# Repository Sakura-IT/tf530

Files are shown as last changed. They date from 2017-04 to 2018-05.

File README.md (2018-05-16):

# TF530 Revision 3

WARNING: This board has not been CE tested. It may cause damage to your A500. I take no responsibility for this. 

This repository contains all the files needed to produce a copy of my accelerator board.

The CPLD Required is a XC9572XL-10VQ64.  The CPLD XC9572XL-10VQG64 is the readily available RoHS "Green" lead-free equivalent.

Everything in this repository is released under the GNU GPLv2. You may create or base commercial PCBs from the work in this repository but you must make the sources for all derivative work available. I have noticed some forks have removed copyright notices. This is a breach of the GPL.

## Firmware / Requirements

  * Xilinx ISE, 14.7 (the final version - other versions may work but this is the one I support)
  * JTAG Adaptor

[For more information visit my channel](https://www.youtube.com/c/TerribleFire)

## License

This project and all the files contained are released under the GNU GPLv2. If you build a modified version of the board you must supply the end user with all the sources (this can be a web link).

## The TerribleFire 530 board (Revision 3)

Completely untested board link.... use with caution!!!! Do not come crying to me if it didnt work!!

http://dirtypcbs.com/store/designer/details/12476/2654/tf530-rev3-zip

## The TerribleFire 530 board (Revision 2)

This board is now in Beta. It may not work in all circumstances but it has been verified to boot AmigaOS 1.3, 2.05 and 3.1 and run various games and desktop apps at 25Mhz. Operation is not guarunteed to be crash free but will work in most "happy path" situations.

I have only verified the HD interface with Compact Flash cards.
I have verified this board boots on Amiga 500 Rev 5, 6a, 8.1a

I accept no responsibiltiy for any damage to any equipment that results from the use of this board. IT IS ENTIRELY AT YOUR OWN RISK!

## Installation

As of Revision 3 installation no longer needs the OVR and INT2 signals connected to the Amiga motherboard. The headers remain on the TF530 for testing but do not need to be connected although it should make little difference if they are connected. Well behaved Autoconfig devices will work alongside the TF530. The autoconfig space asserts the internal OVR signal when there are PICs remaining to be configured. After which the autoconfig will probe the standard bus. This revision should work on the A2000 (untested).

IPL0 has not been routed because we only ever need to assert INT2 and/or INT6.

## What does the board look like

The TF530 Rev 3 looks like...

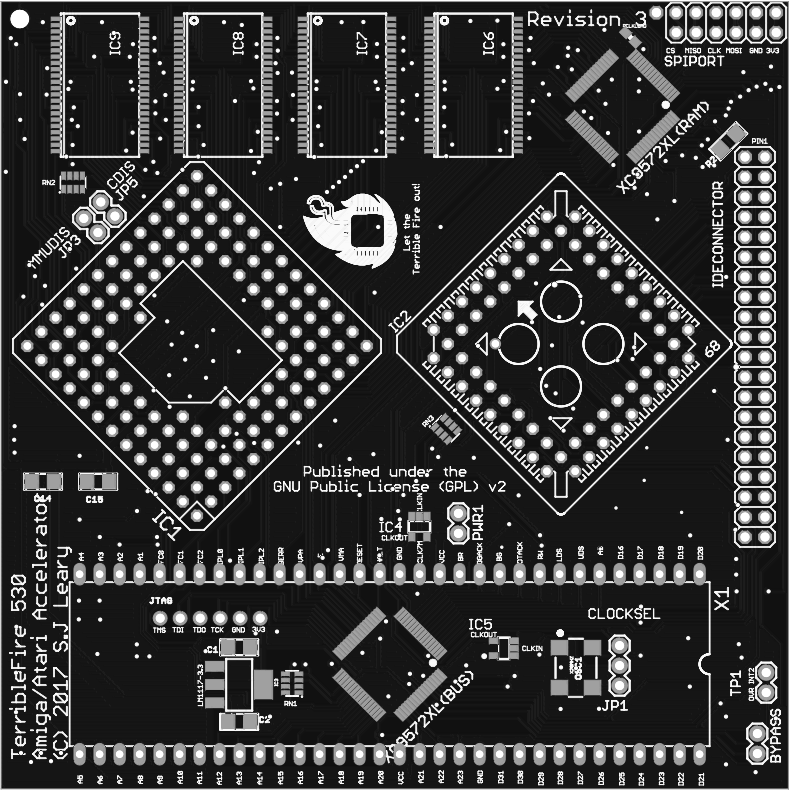
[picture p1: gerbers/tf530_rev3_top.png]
Image of Top of PCB


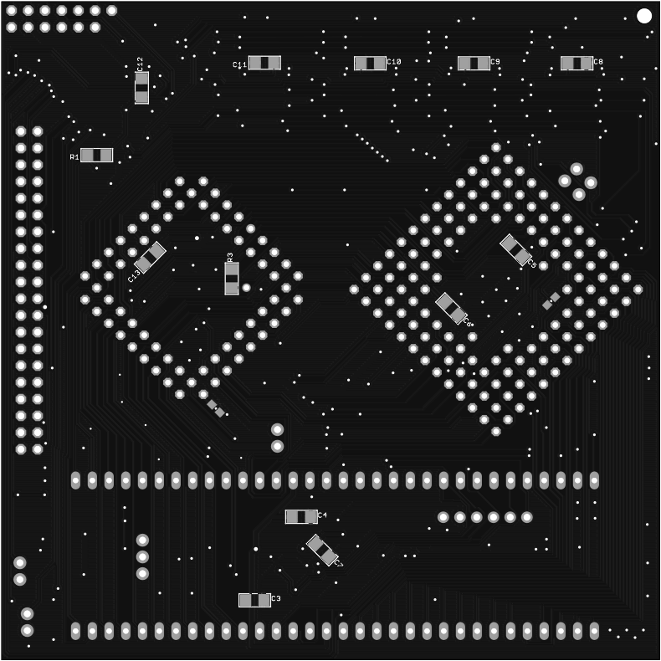
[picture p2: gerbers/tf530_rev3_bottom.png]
Image of Bottom of PCB


## The Rev 3 BOM (WARNING! This is untested)

| Qty | Value | Device | Package | Parts | Description |
|-----|---|---|---|---|---|
| 1 | | MC68030RC | MPGA128 | IC1 | 68030 PROCESSOR |
| 1 | | MC68882FN | PLCC68-S | IC2 | 68882 CO-PROCESSOR (FPU) + PLCC68 Thru Hole Socket |
| 2 | 0.1uF | 0.1UF-25V(+80/-20%)| 0603-CAP | C16, C17 | CAP-00810 |
| 15  | 10uF | CAP_CERAMIC1206 | 1206 | C1, C2, C3, C4, C5, C6, C7, C8, C9, C10, C11, C12, C13, C14, C15 | Ceramic Capacitors |
| 3 | 1K | RESISTOR1206 | 1206 | R1, R2, R3 | Resistors |
| 2 | 74LVC1G17DBV | 74LVC1G17DBV | SOT23-5 | IC4, IC5 | Single Schmitt-Trigger Buffer |
| 4 | AS7C4096A-12TCN | AS7C4096A-12TCN | TSOP44-II | IC6, IC7, IC8, IC9 | SRAM 512k x 8, 5V DO NOT USE ISSI Chips!! |
| 1 | BYPASS | JUMPER-2PTH | 1X02 | BYPASS | Jumper |
| 3 | CAY16-102J4LF | CAY16-102J4LF | RESCAXE80P320X160-8N | RN1, RN2, RN3 | Res Thick Film Array 1K Ohm  |
| 1 | CDIS | JUMPER-2PTH | 1X02 | JP5 | Jumper |
| 1 | CLOCKSEL | JUMPER-3PTH | 1X03 | JP1 | Jumper |
| 1 | EXT5V | JUMPER-2PTH | 1X02 | PWR1 | Jumper |
| 1 | IDE CONNECTOR | PINHD-2X20 | 2X20 | IDECONNECTOR | PIN HEADER |
| 1 | INF | 0.05OHM-1/5W-1% | 0603 | RCLKLOAD | Not Required - Experimental |
| 1 | JTAG | HEADER-1X6ROUND | 1X06_ROUND | JTAG | PIN HEADER |
| 1 | LM1117-3.3 | V_REG_LM1117SOT223 | SOT223 | IC3 | 3.3V Voltage Regulator LM1117 |
| 1 | MC68000 | MC68000P | DIL64 | X1 | 68xxx CPU Slot Strip Headers  |
| 1 | MMUDIS | JUMPER-2PTH | 1X02 | JP3 | Jumper |
| 1 | SPI PORT | PINHD-2X6 | 2X06 | SPIPORT | PIN HEADER |
| 1 | TP1 | JUMPER-2PTH | 1X02 | TP1 | Jumper |
| 1 | X25MHZ | OSCILLATOR | OSC_7X5MM | OSC1 | Oscillator e.g. 25MHz |
| 2 | XC9572XL-VQ64 | XC9572XL-VQ64 | VQ64 | XC9572XL(BUS), XC9572XL(RAM) | Xilinx CPLD |

### Notes

* _The CPU and (optional) FPU must be 25MHz/33Mhz capable._

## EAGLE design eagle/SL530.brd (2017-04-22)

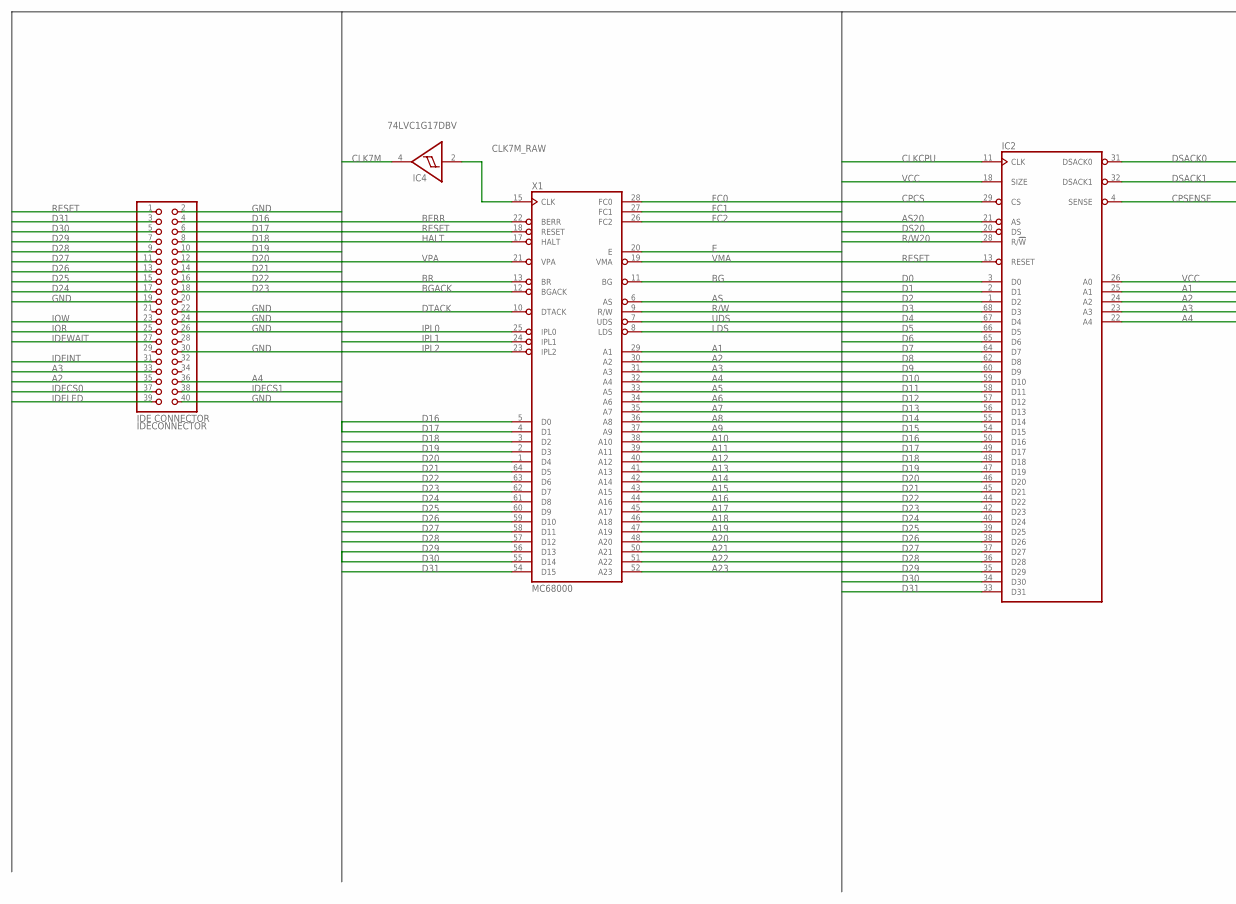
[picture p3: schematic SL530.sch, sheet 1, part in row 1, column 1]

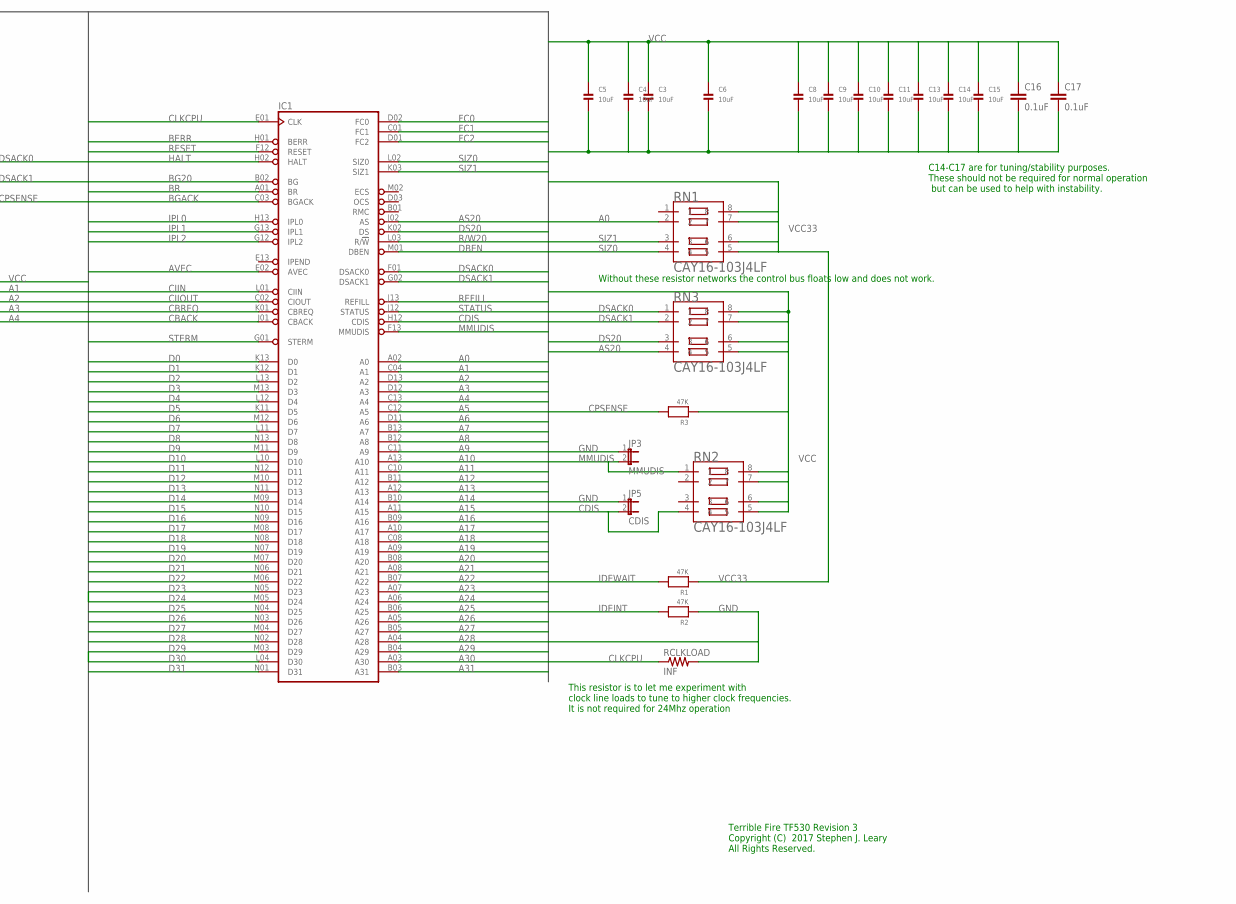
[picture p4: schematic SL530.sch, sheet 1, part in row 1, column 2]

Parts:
C3, C4, C5, C6, C8, C9, C10, C11, C13, C14, C15: 10uF; 1206
C16, C17: 0.1uF; 0603-CAP
IC1: MC68030RC; MPGA128
IC2: MC68881FN-SOC; PLCC68-S
IC4: 74LVC1G17DBV; SOT23-5
IDECONNECTOR: IDE CONNECTOR; 2X20
JP3: MMUDIS; 1X02
JP5: CDIS; 1X02
R1, R2, R3: 47K; 1206
RCLKLOAD: INF; 0603
RN1, RN2, RN3: CAY16-103J4LF; RESCAXE80P320X160-8N
X1: MC68000; DIL64

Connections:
A0: IC1.A02 (A0), RN1.2; also elsewhere on the board
A1: IC1.C04 (A1), IC2.25 (A1), X1.29 (A1); also elsewhere on the board
A2: IC1.D13 (A2), IC2.24 (A2), IDECONNECTOR.35, X1.30 (A2); also elsewhere on the board
A3: IC1.D12 (A3), IC2.23 (A3), IDECONNECTOR.33, X1.31 (A3); also elsewhere on the board
A4: IC1.C13 (A4), IC2.22 (A4), IDECONNECTOR.36, X1.32 (A4); also elsewhere on the board
A5: IC1.C12 (A5), X1.33 (A5); also elsewhere on the board
A6: IC1.D11 (A6), X1.34 (A6); also elsewhere on the board
A7: IC1.B13 (A7), X1.35 (A7); also elsewhere on the board
A8: IC1.B12 (A8), X1.36 (A8); also elsewhere on the board
A9: IC1.C11 (A9), X1.37 (A9); also elsewhere on the board
A10: IC1.A13 (A10), X1.38 (A10); also elsewhere on the board
A11: IC1.C10 (A11), X1.39 (A11); also elsewhere on the board
A12: IC1.B11 (A12), X1.40 (A12); also elsewhere on the board
A13: IC1.A12 (A13), X1.41 (A13); also elsewhere on the board
A14: IC1.B10 (A14), X1.42 (A14); also elsewhere on the board
A15: IC1.A11 (A15), X1.43 (A15); also elsewhere on the board
A16: IC1.B09 (A16), X1.44 (A16); also elsewhere on the board
A17: IC1.A10 (A17), X1.45 (A17); also elsewhere on the board
A18: IC1.C08 (A18), X1.46 (A18); also elsewhere on the board
A19: IC1.A09 (A19), X1.47 (A19); also elsewhere on the board
A20: IC1.B08 (A20), X1.48 (A20); also elsewhere on the board
A21: IC1.A08 (A21), X1.50 (A21); also elsewhere on the board
A22: IC1.B07 (A22), X1.51 (A22); also elsewhere on the board
A23: IC1.A07 (A23), X1.52 (A23); also elsewhere on the board
A24: IC1.A06 (A24)
A25: IC1.B06 (A25)
A26: IC1.A05 (A26)
A27: IC1.B05 (A27)
A28: IC1.A04 (A28)
A29: IC1.B04 (A29)
A30: IC1.A03 (A30)
A31: IC1.B03 (A31)
AS: X1.6 (AS); also elsewhere on the board
AS20: IC1.J02 (AS), IC2.21 (AS), RN3.4; also elsewhere on the board
AVEC: IC1.E02 (AVEC); also elsewhere on the board
BERR: IC1.H01 (BERR), X1.22 (BERR); also elsewhere on the board
BG: X1.11 (BG); also elsewhere on the board
BG20: IC1.B02 (BG); also elsewhere on the board
BGACK: IC1.C03 (BGACK), X1.12 (BGACK); also elsewhere on the board
BR: IC1.A01 (BR), X1.13 (BR)
CBACK: IC1.J01 (CBACK); also elsewhere on the board
CBREQ: IC1.K01 (CBREQ); also elsewhere on the board
CDIS: IC1.H12 (CDIS), JP5.2, RN2.4
CIIN: IC1.L01 (CIIN); also elsewhere on the board
CIIOUT: IC1.C02 (CIOUT)
CLK7M: IC4.4 (O); also elsewhere on the board
CLK7M_RAW: IC4.2 (I), X1.15 (CLK)
CLKCPU: IC1.E01 (CLK), IC2.11 (CLK), RCLKLOAD.1; also elsewhere on the board
CPCS: IC2.29 (CS); also elsewhere on the board
CPSENSE: IC2.4 (SENSE), R3.2; also elsewhere on the board
D0: IC1.K13 (D0), IC2.3 (D0); also elsewhere on the board
D1: IC1.K12 (D1), IC2.2 (D1); also elsewhere on the board
D2: IC1.L13 (D2), IC2.1 (D2); also elsewhere on the board
D3: IC1.M13 (D3), IC2.68 (D3); also elsewhere on the board
D4: IC1.L12 (D4), IC2.67 (D4); also elsewhere on the board
D5: IC1.K11 (D5), IC2.66 (D5); also elsewhere on the board
D6: IC1.M12 (D6), IC2.65 (D6); also elsewhere on the board
D7: IC1.L11 (D7), IC2.64 (D7); also elsewhere on the board
D8: IC1.N13 (D8), IC2.62 (D8); also elsewhere on the board
D9: IC1.M11 (D9), IC2.60 (D9); also elsewhere on the board
D10: IC1.L10 (D10), IC2.59 (D10); also elsewhere on the board
D11: IC1.N12 (D11), IC2.58 (D11); also elsewhere on the board
D12: IC1.M10 (D12), IC2.57 (D12); also elsewhere on the board
D13: IC1.N11 (D13), IC2.56 (D13); also elsewhere on the board
D14: IC1.M09 (D14), IC2.55 (D14); also elsewhere on the board
D15: IC1.N10 (D15), IC2.54 (D15); also elsewhere on the board
D16: IC1.N09 (D16), IC2.50 (D16), IDECONNECTOR.4, X1.5 (D0); also elsewhere on the board
D17: IC1.M08 (D17), IC2.49 (D17), IDECONNECTOR.6, X1.4 (D1); also elsewhere on the board
D18: IC1.N08 (D18), IC2.48 (D18), IDECONNECTOR.8, X1.3 (D2); also elsewhere on the board
D19: IC1.N07 (D19), IC2.47 (D19), IDECONNECTOR.10, X1.2 (D3); also elsewhere on the board
D20: IC1.M07 (D20), IC2.46 (D20), IDECONNECTOR.12, X1.1 (D4); also elsewhere on the board
D21: IC1.N06 (D21), IC2.45 (D21), IDECONNECTOR.14, X1.64 (D5); also elsewhere on the board
D22: IC1.M06 (D22), IC2.44 (D22), IDECONNECTOR.16, X1.63 (D6); also elsewhere on the board
D23: IC1.N05 (D23), IC2.42 (D23), IDECONNECTOR.18, X1.62 (D7); also elsewhere on the board
D24: IC1.M05 (D24), IC2.40 (D24), IDECONNECTOR.17, X1.61 (D8); also elsewhere on the board
D25: IC1.N04 (D25), IC2.39 (D25), IDECONNECTOR.15, X1.60 (D9); also elsewhere on the board
D26: IC1.N03 (D26), IC2.38 (D26), IDECONNECTOR.13, X1.59 (D10); also elsewhere on the board
D27: IC1.M04 (D27), IC2.37 (D27), IDECONNECTOR.11, X1.58 (D11); also elsewhere on the board
D28: IC1.N02 (D28), IC2.36 (D28), IDECONNECTOR.9, X1.57 (D12); also elsewhere on the board
D29: IC1.M03 (D29), IC2.35 (D29), IDECONNECTOR.7, X1.56 (D13); also elsewhere on the board
D30: IC1.L04 (D30), IC2.34 (D30), IDECONNECTOR.5, X1.55 (D14); also elsewhere on the board
D31: IC1.N01 (D31), IC2.33 (D31), IDECONNECTOR.3, X1.54 (D15); also elsewhere on the board
DBEN: IC1.M01 (DBEN)
DS20: IC1.K02 (DS), IC2.20 (DS), RN3.3; also elsewhere on the board
DSACK0: IC1.F01 (DSACK0), IC2.31 (DSACK0), RN3.1
DSACK1: IC1.G02 (DSACK1), IC2.32 (DSACK1), RN3.2; also elsewhere on the board
DTACK: X1.10 (DTACK); also elsewhere on the board
E: X1.20 (E); also elsewhere on the board
FC0: IC1.D02 (FC0), X1.28 (FC0); also elsewhere on the board
FC1: IC1.C01 (FC1), X1.27 (FC1); also elsewhere on the board
FC2: IC1.D01 (FC2), X1.26 (FC2); also elsewhere on the board
GND: C3.2, C4.2, C5.2, C6.2, C8.2, C9.2, C10.2, C11.2, C13.2, C14.2, C15.2, C16.2, C17.2, IC1.C05 (GND), IC1.C07 (GND), IC1.C09 (GND), IC1.E03 (GND), IC1.E11 (GND), IC1.F03 (GND), IC1.G03 (GND), IC1.G11 (GND), IC1.J03 (GND), IC1.J11 (GND), IC1.L05 (GND), IC1.L07 (GND), IC1.L08 (GND), IC1.L09 (GND), IC2.5 (GND), IC2.6 (GND), IC2.7 (GND), IC2.8 (GND), IC2.9 (GND), IC2.12 (GND), IC2.14 (GND), IC2.19 (GND), IC2.30 (GND), IC2.41 (GND), IC2.51 (GND), IC2.63 (GND), IC4.3 (GND), IDECONNECTOR.2, IDECONNECTOR.19, IDECONNECTOR.22, IDECONNECTOR.24, IDECONNECTOR.26, IDECONNECTOR.30, IDECONNECTOR.40, JP3.1, JP5.1, R2.1, RCLKLOAD.2, X1.16 (GND), X1.53 (GND); also elsewhere on the board
HALT: IC1.H02 (HALT), X1.17 (HALT); also elsewhere on the board
IDECS0: IDECONNECTOR.37; also elsewhere on the board
IDECS1: IDECONNECTOR.38; also elsewhere on the board
IDEINT: IDECONNECTOR.31, R2.2; also elsewhere on the board
IDELED: IDECONNECTOR.39
IDEWAIT: IDECONNECTOR.27, R1.2; also elsewhere on the board
IOR: IDECONNECTOR.25; also elsewhere on the board
IOW: IDECONNECTOR.23; also elsewhere on the board
IPL0: IC1.H13 (IPL0), X1.25 (IPL0)
IPL1: IC1.G13 (IPL1), X1.24 (IPL1); also elsewhere on the board
IPL2: IC1.G12 (IPL2), X1.23 (IPL2); also elsewhere on the board
LDS: X1.8 (LDS); also elsewhere on the board
MMUDIS: IC1.F13 (MMUDIS), JP3.2, RN2.1
R/W: X1.9 (R/W); also elsewhere on the board
R/W20: IC1.L03 (R/!W), IC2.28 (R/!W); also elsewhere on the board
REFILL: IC1.J13 (REFILL)
RESET: IC1.F12 (RESET), IC2.13 (RESET), IDECONNECTOR.1, X1.18 (RESET); also elsewhere on the board
SIZ0: IC1.L02 (SIZ0), RN1.4; also elsewhere on the board
SIZ1: IC1.K03 (SIZ1), RN1.3; also elsewhere on the board
STATUS: IC1.J12 (STATUS)
STERM: IC1.G01 (STERM); also elsewhere on the board
UDS: X1.7 (UDS); also elsewhere on the board
VCC: C3.1, C4.1, C5.1, C6.1, C8.1, C9.1, C10.1, C11.1, C13.1, C14.1, C15.1, C16.1, C17.1, IC1.C06 (VCC), IC1.D04 (VCC), IC1.D10 (VCC), IC1.F02 (VCC), IC1.F11 (VCC), IC1.H03 (VCC), IC1.H11 (VCC), IC1.K04 (VCC), IC1.K10 (VCC), IC1.L06 (VCC), IC2.10 (VCC), IC2.16 (VCC), IC2.17 (VCC), IC2.18 (SIZE), IC2.26 (A0), IC2.27 (VCC), IC2.43 (VCC), IC2.52 (VCC), IC2.53 (VCC), IC2.61 (VCC), IC4.5 (VCC), R3.1, RN2.5, RN2.6, RN2.7, RN2.8, RN3.5, RN3.6, RN3.7, RN3.8, X1.14 (VCC), X1.49 (VCC); also elsewhere on the board
VCC33: R1.1, RN1.5, RN1.6, RN1.7, RN1.8; also elsewhere on the board
VMA: X1.19 (VMA); also elsewhere on the board
VPA: X1.21 (VPA); also elsewhere on the board

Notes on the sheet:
This resistor is to let me experiment with clock line loads to tune to higher clock frequencies. It is not required for 24Mhz operation
C14-C17 are for tuning/stability purposes. These should not be required for normal operation but can be used to help with instability.
Without these resistor networks the control bus floats low and does not work.
Terrible Fire TF530 Revision 3 Copyright (C) 2017 Stephen J. Leary All Rights Reserved.

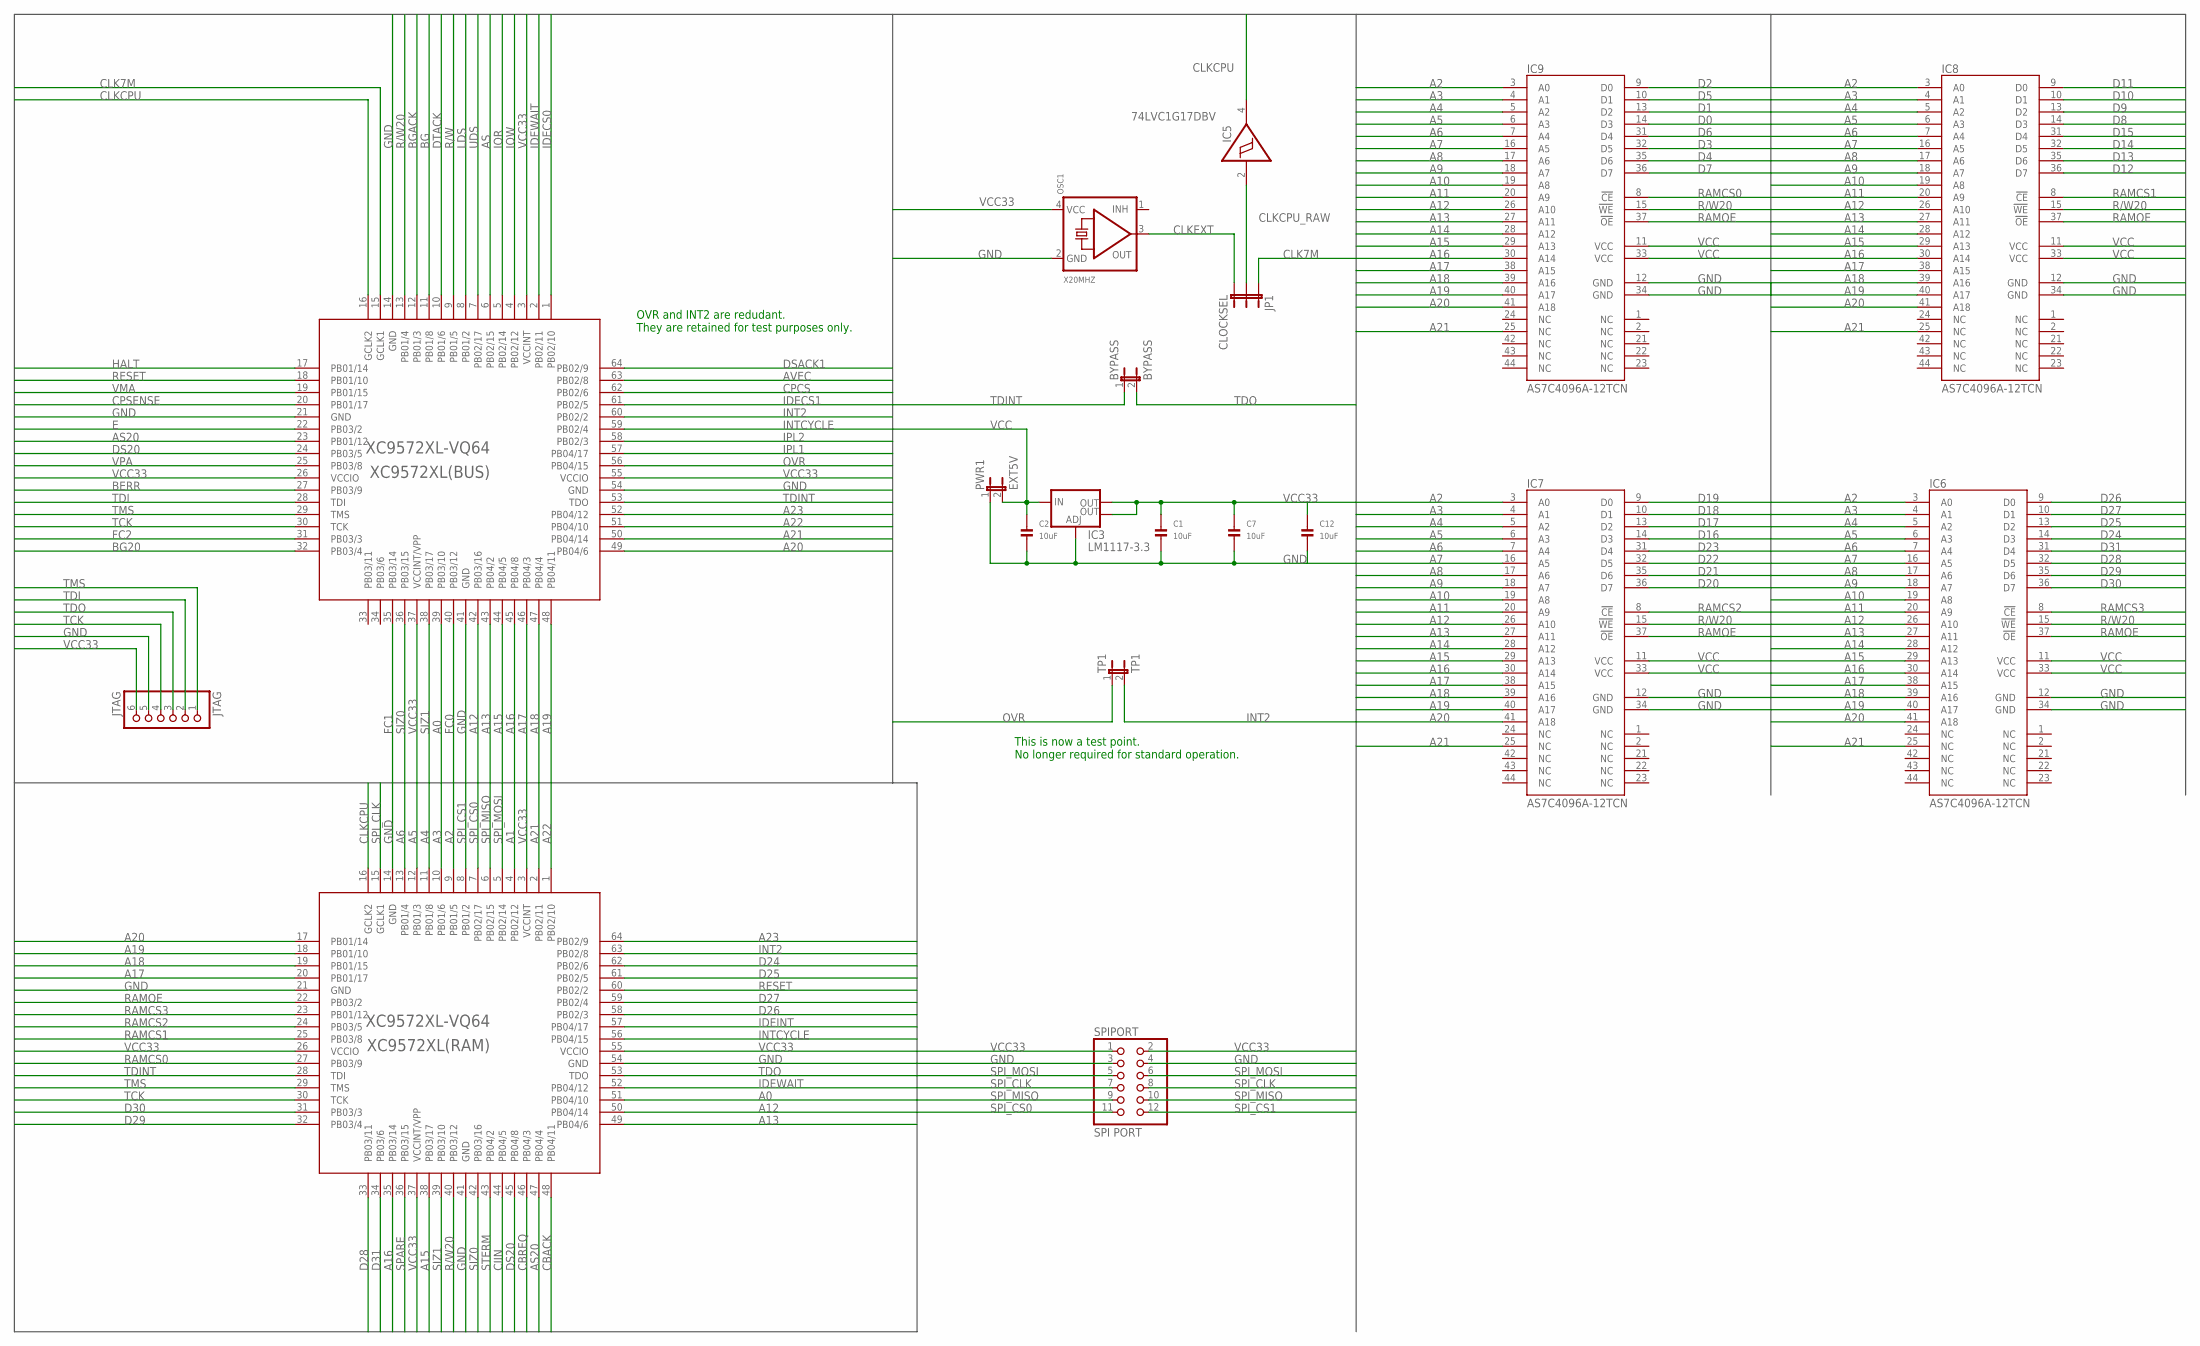
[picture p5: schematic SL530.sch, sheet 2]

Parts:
BYPASS: BYPASS; 1X02
C1, C2, C7, C12: 10uF; 1206
IC3: LM1117-3.3; SOT223
IC5: 74LVC1G17DBV; SOT23-5
IC6, IC7, IC8, IC9: AS7C4096A-12TCN; TSOP44-II
JP1: CLOCKSEL; 1X03
JTAG: JTAG; 1X06_ROUND
OSC1: X20MHZ; OSC_7X5MM
PWR1: EXT5V; 1X02
SPIPORT: SPI PORT; 2X06
TP1: TP1; 1X02
XC9572XL(BUS), XC9572XL(RAM): XC9572XL-VQ64; VQ64

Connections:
A0: XC9572XL(BUS).39 (PB03/10), XC9572XL(RAM).51 (PB04/10); also elsewhere on the board
A1: XC9572XL(RAM).4 (PB02/12); also elsewhere on the board
A2: IC6.3 (A0), IC7.3 (A0), IC8.3 (A0), IC9.3 (A0), XC9572XL(RAM).9 (PB01/5); also elsewhere on the board
A3: IC6.4 (A1), IC7.4 (A1), IC8.4 (A1), IC9.4 (A1), XC9572XL(RAM).10 (PB01/6); also elsewhere on the board
A4: IC6.5 (A2), IC7.5 (A2), IC8.5 (A2), IC9.5 (A2), XC9572XL(RAM).11 (PB01/8); also elsewhere on the board
A5: IC6.6 (A3), IC7.6 (A3), IC8.6 (A3), IC9.6 (A3), XC9572XL(RAM).12 (PB01/3); also elsewhere on the board
A6: IC6.7 (A4), IC7.7 (A4), IC8.7 (A4), IC9.7 (A4), XC9572XL(RAM).13 (PB01/4); also elsewhere on the board
A7: IC6.16 (A5), IC7.16 (A5), IC8.16 (A5), IC9.16 (A5); also elsewhere on the board
A8: IC6.17 (A6), IC7.17 (A6), IC8.17 (A6), IC9.17 (A6); also elsewhere on the board
A9: IC6.18 (A7), IC7.18 (A7), IC8.18 (A7), IC9.18 (A7); also elsewhere on the board
A10: IC6.19 (A8), IC7.19 (A8), IC8.19 (A8), IC9.19 (A8); also elsewhere on the board
A11: IC6.20 (A9), IC7.20 (A9), IC8.20 (A9), IC9.20 (A9); also elsewhere on the board
A12: IC6.26 (A10), IC7.26 (A10), IC8.26 (A10), IC9.26 (A10), XC9572XL(BUS).42 (PB03/16), XC9572XL(RAM).50 (PB04/14); also elsewhere on the board
A13: IC6.27 (A11), IC7.27 (A11), IC8.27 (A11), IC9.27 (A11), XC9572XL(BUS).43 (PB04/2), XC9572XL(RAM).49 (PB04/6); also elsewhere on the board
A14: IC6.28 (A12), IC7.28 (A12), IC8.28 (A12), IC9.28 (A12); also elsewhere on the board
A15: IC6.29 (A13), IC7.29 (A13), IC8.29 (A13), IC9.29 (A13), XC9572XL(BUS).44 (PB04/5), XC9572XL(RAM).38 (PB03/17); also elsewhere on the board
A16: IC6.30 (A14), IC7.30 (A14), IC8.30 (A14), IC9.30 (A14), XC9572XL(BUS).45 (PB04/8), XC9572XL(RAM).35 (PB03/14); also elsewhere on the board
A17: IC6.38 (A15), IC7.38 (A15), IC8.38 (A15), IC9.38 (A15), XC9572XL(BUS).46 (PB04/3), XC9572XL(RAM).20 (PB01/17); also elsewhere on the board
A18: IC6.39 (A16), IC7.39 (A16), IC8.39 (A16), IC9.39 (A16), XC9572XL(BUS).47 (PB04/4), XC9572XL(RAM).19 (PB01/15); also elsewhere on the board
A19: IC6.40 (A17), IC7.40 (A17), IC8.40 (A17), IC9.40 (A17), XC9572XL(BUS).48 (PB04/11), XC9572XL(RAM).18 (PB01/10); also elsewhere on the board
A20: IC6.41 (A18), IC7.41 (A18), IC8.41 (A18), IC9.41 (A18), XC9572XL(BUS).49 (PB04/6), XC9572XL(RAM).17 (PB01/14); also elsewhere on the board
A21: IC6.25 (NC), IC7.25 (NC), IC8.25 (NC), IC9.25 (NC), XC9572XL(BUS).50 (PB04/14), XC9572XL(RAM).2 (PB02/11); also elsewhere on the board
A22: XC9572XL(BUS).51 (PB04/10), XC9572XL(RAM).1 (PB02/10); also elsewhere on the board
A23: XC9572XL(BUS).52 (PB04/12), XC9572XL(RAM).64 (PB02/9); also elsewhere on the board
AS: XC9572XL(BUS).6 (PB02/15); also elsewhere on the board
AS20: XC9572XL(BUS).23 (PB01/12), XC9572XL(RAM).47 (PB04/4); also elsewhere on the board
AVEC: XC9572XL(BUS).63 (PB02/8); also elsewhere on the board
BERR: XC9572XL(BUS).27 (PB03/9); also elsewhere on the board
BG: XC9572XL(BUS).11 (PB01/8); also elsewhere on the board
BG20: XC9572XL(BUS).32 (PB03/4); also elsewhere on the board
BGACK: XC9572XL(BUS).12 (PB01/3); also elsewhere on the board
CBACK: XC9572XL(RAM).48 (PB04/11); also elsewhere on the board
CBREQ: XC9572XL(RAM).46 (PB04/3); also elsewhere on the board
CIIN: XC9572XL(RAM).44 (PB04/5); also elsewhere on the board
CLK7M: JP1.1, XC9572XL(BUS).15 (GCLK1); also elsewhere on the board
CLKCPU: IC5.4 (O), XC9572XL(BUS).16 (GCLK2), XC9572XL(RAM).16 (GCLK2); also elsewhere on the board
CLKCPU_RAW: IC5.2 (I), JP1.2
CLKEXT: JP1.3, OSC1.3 (OUT)
CPCS: XC9572XL(BUS).62 (PB02/6); also elsewhere on the board
CPSENSE: XC9572XL(BUS).20 (PB01/17); also elsewhere on the board
D0: IC9.14 (D3); also elsewhere on the board
D1: IC9.13 (D2); also elsewhere on the board
D2: IC9.9 (D0); also elsewhere on the board
D3: IC9.32 (D5); also elsewhere on the board
D4: IC9.35 (D6); also elsewhere on the board
D5: IC9.10 (D1); also elsewhere on the board
D6: IC9.31 (D4); also elsewhere on the board
D7: IC9.36 (D7); also elsewhere on the board
D8: IC8.14 (D3); also elsewhere on the board
D9: IC8.13 (D2); also elsewhere on the board
D10: IC8.10 (D1); also elsewhere on the board
D11: IC8.9 (D0); also elsewhere on the board
D12: IC8.36 (D7); also elsewhere on the board
D13: IC8.35 (D6); also elsewhere on the board
D14: IC8.32 (D5); also elsewhere on the board
D15: IC8.31 (D4); also elsewhere on the board
D16: IC7.14 (D3); also elsewhere on the board
D17: IC7.13 (D2); also elsewhere on the board
D18: IC7.10 (D1); also elsewhere on the board
D19: IC7.9 (D0); also elsewhere on the board
D20: IC7.36 (D7); also elsewhere on the board
D21: IC7.35 (D6); also elsewhere on the board
D22: IC7.32 (D5); also elsewhere on the board
D23: IC7.31 (D4); also elsewhere on the board
D24: IC6.14 (D3), XC9572XL(RAM).62 (PB02/6); also elsewhere on the board
D25: IC6.13 (D2), XC9572XL(RAM).61 (PB02/5); also elsewhere on the board
D26: IC6.9 (D0), XC9572XL(RAM).58 (PB02/3); also elsewhere on the board
D27: IC6.10 (D1), XC9572XL(RAM).59 (PB02/4); also elsewhere on the board
D28: IC6.32 (D5), XC9572XL(RAM).33 (PB03/11); also elsewhere on the board
D29: IC6.35 (D6), XC9572XL(RAM).32 (PB03/4); also elsewhere on the board
D30: IC6.36 (D7), XC9572XL(RAM).31 (PB03/3); also elsewhere on the board
D31: IC6.31 (D4), XC9572XL(RAM).34 (PB03/6); also elsewhere on the board
DS20: XC9572XL(BUS).24 (PB03/5), XC9572XL(RAM).45 (PB04/8); also elsewhere on the board
DSACK1: XC9572XL(BUS).64 (PB02/9); also elsewhere on the board
DTACK: XC9572XL(BUS).10 (PB01/6); also elsewhere on the board
E: XC9572XL(BUS).22 (PB03/2); also elsewhere on the board
FC0: XC9572XL(BUS).40 (PB03/12); also elsewhere on the board
FC1: XC9572XL(BUS).35 (PB03/14); also elsewhere on the board
FC2: XC9572XL(BUS).31 (PB03/3); also elsewhere on the board
GND: C1.2, C2.2, C7.2, C12.2, IC3.1 (ADJ), IC5.3 (GND), IC6.12 (GND), IC6.34 (GND), IC7.12 (GND), IC7.34 (GND), IC8.12 (GND), IC8.34 (GND), IC9.12 (GND), IC9.34 (GND), JTAG.5, OSC1.2 (GND), PWR1.1, SPIPORT.3, SPIPORT.4, XC9572XL(BUS).14 (GND), XC9572XL(BUS).21 (GND), XC9572XL(BUS).41 (GND), XC9572XL(BUS).54 (GND), XC9572XL(RAM).14 (GND), XC9572XL(RAM).21 (GND), XC9572XL(RAM).41 (GND), XC9572XL(RAM).54 (GND); also elsewhere on the board
HALT: XC9572XL(BUS).17 (PB01/14); also elsewhere on the board
IDECS0: XC9572XL(BUS).1 (PB02/10); also elsewhere on the board
IDECS1: XC9572XL(BUS).61 (PB02/5); also elsewhere on the board
IDEINT: XC9572XL(RAM).57 (PB04/17); also elsewhere on the board
IDEWAIT: XC9572XL(BUS).2 (PB02/11), XC9572XL(RAM).52 (PB04/12); also elsewhere on the board
INT2: TP1.2, XC9572XL(BUS).60 (PB02/2), XC9572XL(RAM).63 (PB02/8)
INTCYCLE: XC9572XL(BUS).59 (PB02/4), XC9572XL(RAM).56 (PB04/15)
IOR: XC9572XL(BUS).5 (PB02/14); also elsewhere on the board
IOW: XC9572XL(BUS).4 (PB02/12); also elsewhere on the board
IPL1: XC9572XL(BUS).57 (PB04/17); also elsewhere on the board
IPL2: XC9572XL(BUS).58 (PB02/3); also elsewhere on the board
LDS: XC9572XL(BUS).8 (PB01/2); also elsewhere on the board
OVR: TP1.1, XC9572XL(BUS).56 (PB04/15)
R/W: XC9572XL(BUS).9 (PB01/5); also elsewhere on the board
R/W20: IC6.15 (!WE), IC7.15 (!WE), IC8.15 (!WE), IC9.15 (!WE), XC9572XL(BUS).13 (PB01/4), XC9572XL(RAM).40 (PB03/12); also elsewhere on the board
RAMCS0: IC9.8 (!CE), XC9572XL(RAM).27 (PB03/9)
RAMCS1: IC8.8 (!CE), XC9572XL(RAM).25 (PB03/8)
RAMCS2: IC7.8 (!CE), XC9572XL(RAM).24 (PB03/5)
RAMCS3: IC6.8 (!CE), XC9572XL(RAM).23 (PB01/12)
RAMOE: IC6.37 (!OE), IC7.37 (!OE), IC8.37 (!OE), IC9.37 (!OE), XC9572XL(RAM).22 (PB03/2)
RESET: XC9572XL(BUS).18 (PB01/10), XC9572XL(RAM).60 (PB02/2); also elsewhere on the board
SIZ0: XC9572XL(BUS).36 (PB03/15), XC9572XL(RAM).42 (PB03/16); also elsewhere on the board
SIZ1: XC9572XL(BUS).38 (PB03/17), XC9572XL(RAM).39 (PB03/10); also elsewhere on the board
SPARE: XC9572XL(RAM).36 (PB03/15)
SPI_CLK: SPIPORT.7, SPIPORT.8, XC9572XL(RAM).15 (GCLK1)
SPI_CS0: SPIPORT.11, XC9572XL(RAM).7 (PB02/17)
SPI_CS1: SPIPORT.12, XC9572XL(RAM).8 (PB01/2)
SPI_MISO: SPIPORT.9, SPIPORT.10, XC9572XL(RAM).6 (PB02/15)
SPI_MOSI: SPIPORT.5, SPIPORT.6, XC9572XL(RAM).5 (PB02/14)
STERM: XC9572XL(RAM).43 (PB04/2); also elsewhere on the board
TCK: JTAG.4, XC9572XL(BUS).30 (TCK), XC9572XL(RAM).30 (TCK)
TDI: JTAG.2, XC9572XL(BUS).28 (TDI)
TDINT: BYPASS.1, XC9572XL(BUS).53 (TDO), XC9572XL(RAM).28 (TDI)
TDO: BYPASS.2, JTAG.3, XC9572XL(RAM).53 (TDO)
TMS: JTAG.1, XC9572XL(BUS).29 (TMS), XC9572XL(RAM).29 (TMS)
UDS: XC9572XL(BUS).7 (PB02/17); also elsewhere on the board
VCC: C2.1, IC3.3 (IN), IC5.5 (VCC), IC6.11 (VCC), IC6.33 (VCC), IC7.11 (VCC), IC7.33 (VCC), IC8.11 (VCC), IC8.33 (VCC), IC9.11 (VCC), IC9.33 (VCC), PWR1.2; also elsewhere on the board
VCC33: C1.1, C7.1, C12.1, IC3.2 (OUT), IC3.4 (OUT), JTAG.6, OSC1.4 (VCC), SPIPORT.1, SPIPORT.2, XC9572XL(BUS).3 (VCCINT), XC9572XL(BUS).26 (VCCIO), XC9572XL(BUS).37 (VCCINT/VPP), XC9572XL(BUS).55 (VCCIO), XC9572XL(RAM).3 (VCCINT), XC9572XL(RAM).26 (VCCIO), XC9572XL(RAM).37 (VCCINT/VPP), XC9572XL(RAM).55 (VCCIO); also elsewhere on the board
VMA: XC9572XL(BUS).19 (PB01/15); also elsewhere on the board
VPA: XC9572XL(BUS).25 (PB03/8); also elsewhere on the board

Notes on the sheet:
OVR and INT2 are redudant. They are retained for test purposes only.
This is now a test point. No longer required for standard operation.

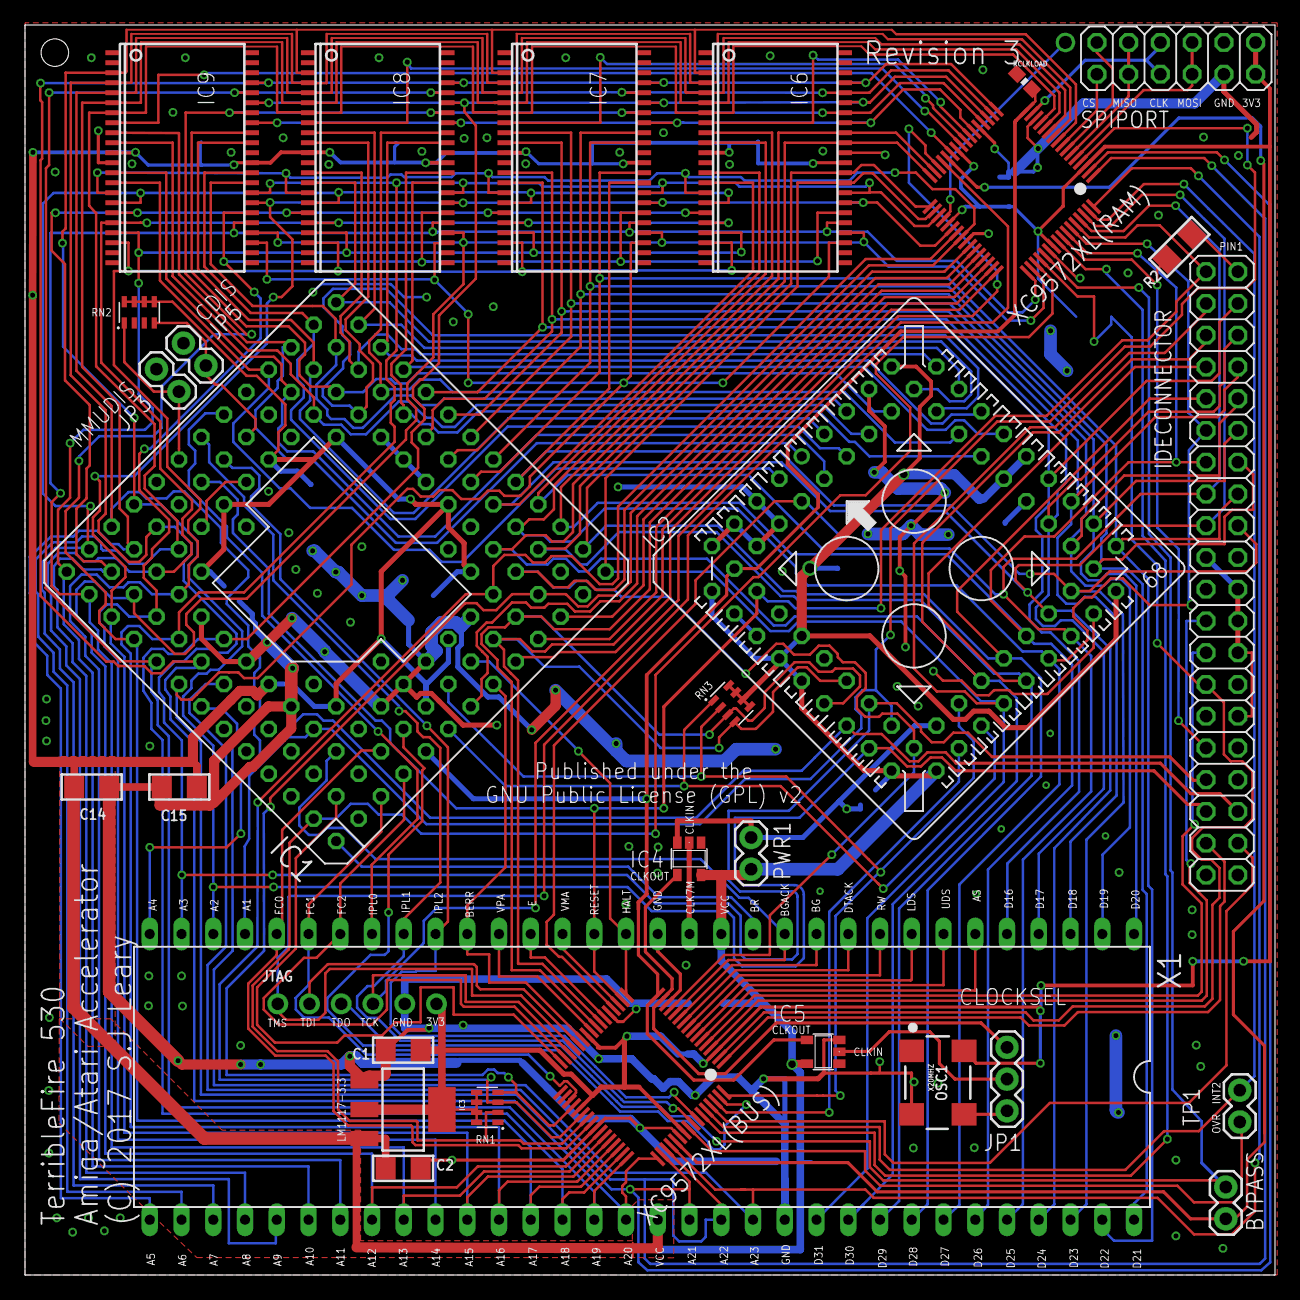
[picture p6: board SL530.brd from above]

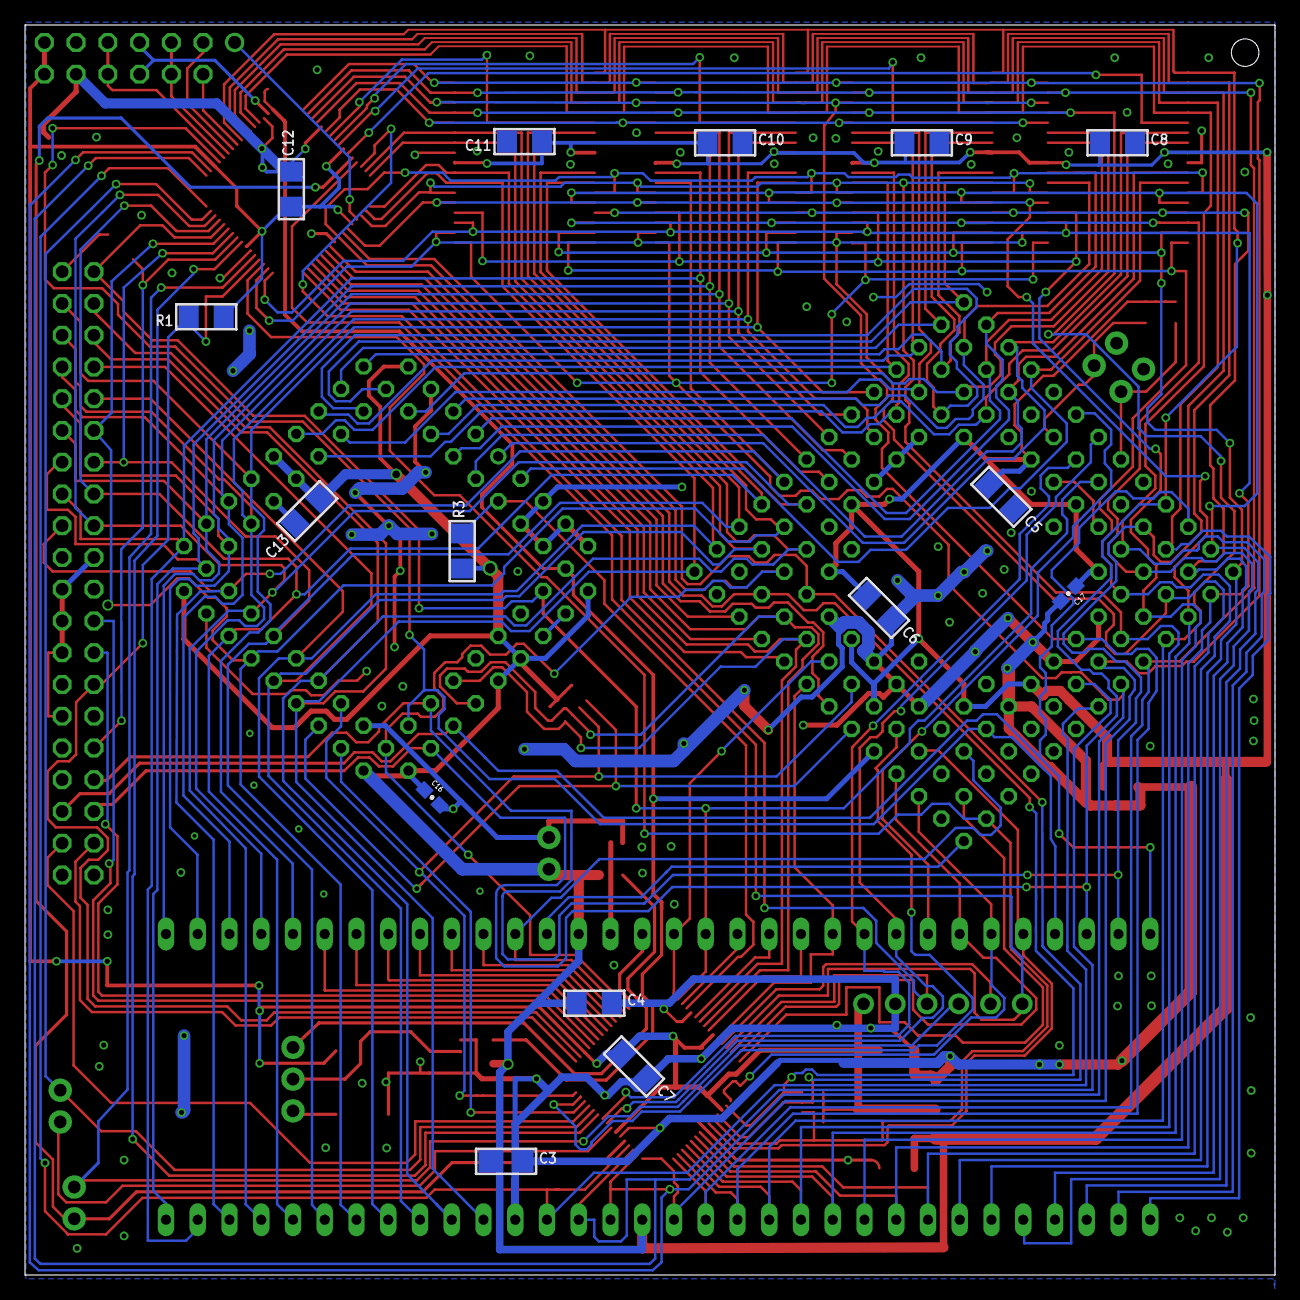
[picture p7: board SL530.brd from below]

Board: 2 copper layers, 100.0 x 100.0 mm, 46 parts (15 on the bottom side), 125 nets.

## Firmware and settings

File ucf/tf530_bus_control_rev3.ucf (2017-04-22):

# Copyright (C) 2016-2017, Stephen J. Leary
# All rights reserved.
#
# This file is part of TF530 (Terrible Fire 030 Accelerator)
#
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
NET "A0"      LOC="39";
NET "A<12>"      LOC="42";
NET "A<13>"      LOC="43";
NET "A<15>"      LOC="44";
NET "A<16>"      LOC="45";
NET "A<17>"      LOC="46";
NET "A<18>"      LOC="47";
NET "A<19>"      LOC="48";
NET "A<20>"      LOC="49";
NET "A<21>"      LOC="50";
NET "A<22>"      LOC="51";
NET "A<23>"      LOC="52";
NET "AS"      LOC="6";
NET "AS20"      LOC="23";
NET "AVEC"      LOC="63";
NET "BERR"      LOC="27";
NET "BG"      LOC="11";
NET "BG20"      LOC="32";
NET "BGACK"      LOC="12";
NET "CPCS"      LOC="62";
NET "CPSENSE"      LOC="20";
NET "DS20"      LOC="24";
NET "DSACK<1>"      LOC="64";
NET "DTACK"      LOC="10";
NET "E"      LOC="22";
NET "FC<0>"      LOC="40";
NET "FC<1>"      LOC="35";
NET "FC<2>"      LOC="31";
#NET "HALT"      LOC="17";
NET "IDECS<0>"      LOC="1";
NET "IDECS<1>"      LOC="61";
NET "IDEWAIT"      LOC="2";
#NET "INT2"      LOC="60";
NET "INTSIG"      LOC="59";
NET "IOR"      LOC="5";
NET "IOW"      LOC="4";
NET "IPL<1>"      LOC="57";
NET "IPL<2>"      LOC="58";
NET "LDS"      LOC="8";
NET "OVR"      LOC="56";
NET "RW00"      LOC="9";
NET "RW20"      LOC="13";
#NET "RESET"      LOC="18";
NET "SIZ<0>"      LOC="36";
NET "SIZ<1>"      LOC="38";
NET "UDS"      LOC="7";
NET "VMA"      LOC="19";
NET "VPA"      LOC="25";

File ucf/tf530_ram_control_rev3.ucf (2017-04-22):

# Copyright (C) 2016-2017, Stephen J. Leary
# All rights reserved.
#
# This file is part of TF530 (Terrible Fire 030 Accelerator)
#
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
#Clocks
NET "CLKCPU"		LOC="16";
NET "CLKCPU" BUFG=CLK;
NET "CLKCPU" TNM_NET = "CLKCPU"; # gives the net clk a group name as CLKCPU
TIMESPEC "TS_CLKCPU" = PERIOD "CLKCPU" 20 ns ; # add 20 ns PERIOD constraint the
OFFSET = IN 5 ns BEFORE "CLKCPU" ; # add  offset in constraint
OFFSET = OUT 5 ns AFTER "CLKCPU" ; # add  offset out constraint
NET "A0"      LOC="51";
NET "A1"      LOC="4";
NET "AB<2>"      LOC="9";
NET "AB<3>"      LOC="10";
NET "AB<4>"      LOC="11";
NET "AB<5>"      LOC="12";
NET "AB<6>"      LOC="13";
NET "A<12>"      LOC="50";
NET "A<13>"      LOC="49";
NET "A<15>"      LOC="38";
NET "A<16>"      LOC="35";
NET "A<17>"      LOC="20";
NET "A<18>"      LOC="19";
NET "A<19>"      LOC="18";
NET "A<20>"      LOC="17";
NET "A<21>"      LOC="2";
NET "A<22>"      LOC="1";
NET "A<23>"      LOC="64";
NET "AS20"      LOC="47";
NET "CBACK"      LOC="48";
NET "CBREQ"      LOC="46";
NET "CIIN"      LOC="44";
NET "D<0>"      LOC="62";
NET "D<1>"      LOC="61";
NET "D<2>"      LOC="58";
NET "D<3>"      LOC="59";
NET "D<4>"      LOC="33";
NET "D<5>"      LOC="32";
NET "D<6>"      LOC="31";
NET "D<7>"      LOC="34";
NET "DS20"      LOC="45";
NET "IDEINT"      LOC="57";
NET "IDEWAIT"      LOC="52";
NET "INT2"      LOC="63";
NET "INTCYCLE"      LOC="56";
NET "RW20"      LOC="40";
NET "RAMCS<0>"      LOC="27";
NET "RAMCS<1>"      LOC="25";
NET "RAMCS<2>"      LOC="24";
NET "RAMCS<3>"      LOC="23";
NET "RAMOE"      LOC="22";
NET "RESET"      LOC="60";
NET "SIZ<0>"      LOC="42";
NET "SIZ<1>"      LOC="39";
NET "SPARE"      LOC="36";
NET "SPI_CLK"      LOC="15";
NET "SPI_CS<0>"      LOC="7";
NET "SPI_CS<1>"      LOC="8";
NET "SPI_MISO"      LOC="6";
NET "SPI_MOSI"      LOC="5";
NET "STERM"      LOC="43";

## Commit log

2017-04-13 updated the dot on the silkscreen
    [SL530.brd]
2017-04-13 updated the silkscreen
    [SL530.sch]
2017-04-13 fixed the silkscreen
    [SL530.brd, SL530.sch]
2017-04-22 Modifications to the TF530. upgrade to eagle 8. Added IPL lines to the bus CPLD. Significant re-routing of the Bus CPLD traces. Incremented version to revision 3 Beefed up power rails. improved routi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
    No CPLD updates yet.. to follow.
    Added 2 more decoupling caps for the 030
    Removed unused DSACK1/A14/AUX0/AUX1
    I have left in OVR and INT2 for test purposes.
    These shouldn't need connected.
    removed the test traces for A14
    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
    [SL530.brd, SL530.sch]
2017-04-22 Bit of a clean up of the silkscreen Really beefed up VCC to the CPU more ground beefing added an experimental (optional) resistor to load the CPU clock line. added 2 more 0603 caps. One for the CPU a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
    Bit more tidy up on the routing around the bus cpld.
    [SL530.brd, SL530.sch]
2017-04-22 Dirty PCB images of TF530 Rev 3
2017-06-19 update rev3 bom (untested) (#3)
    * update rev3 bom (untested)
    * Change R1->1K to fix IDEWAIT pullup
2017-12-02 Update Untested BOM (#5)
    One less thing for people to complain about.
2018-01-01 Update README.md
    Correcting error in BOM.

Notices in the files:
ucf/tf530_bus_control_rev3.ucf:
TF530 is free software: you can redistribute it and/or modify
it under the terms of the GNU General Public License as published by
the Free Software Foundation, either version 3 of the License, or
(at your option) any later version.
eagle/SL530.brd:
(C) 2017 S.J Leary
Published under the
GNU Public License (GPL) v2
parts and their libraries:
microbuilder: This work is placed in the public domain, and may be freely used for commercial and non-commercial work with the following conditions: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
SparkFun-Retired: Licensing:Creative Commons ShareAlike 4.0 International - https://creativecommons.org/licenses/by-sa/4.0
